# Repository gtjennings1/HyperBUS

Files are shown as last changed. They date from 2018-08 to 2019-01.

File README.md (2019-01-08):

# HyperRAM
A basic HyperRAM controller for Lattice iCE40 Ultraplus FPGAs

You can download a Verilog model of the Cypress HyperRAM from their website.
http://www.cypress.com/verilog/s27kl0641-verilog

	bitstream/	- Contains pre-synthesized and compiled FPGA bitstream and RISC-V firmware files

	radiant/		- Lattice Radiant project of the RISC-V + HyperRAM controller design

	iCEStorm/	- iCEStorm project of the RISC-V + HyperRAM controller design

	riscv32/		- picorv32 and picoSoC RISC-V files

	simulation/	- Simulation of standalone controller

	standalone/	- Simple HyperRam Controller

Sources:
RISC-V examples were based off of the PicoSoC examples provided by mmicko at the Hackaday FPGA101 Workshop.  Thank you for the great examples mmicko!
https://github.com/mmicko/fpga101-workshop

## How do I use this project

This project provide examples for APIO and iCEStorm projects and also The Lattice Radiant sotware.

### Build and upload under iCEStorm 
1. Install iCEStorm (http://www.clifford.at/icestorm/)
2. Run the following commands
    cd ./icestorm
    ./hyperram.sh
    iceprog hyperram.bin

### Build and upload under APIO project
1. Install APIO (https://github.com/FPGAwars/apio)
2. Run the following commands
    cd ./riscv32/hardware
    apio build
    apio upload

### Build and upload under Radiant software
1. Install the Laticce Radiant software (http://www.latticesemi.com/Products/DesignSoftwareAndIP/FPGAandLDS/Radiant)
2. Open radiant/riscv32_radiant.rdf file
3. Build and upload the project using the Radiant Software

### Build and upload the software for RISCV32 
1. If you use the APIO project:
    cd ./riscv32/software
    apio make
    apio make upload

2. In other cases 
   riscv64-unknown-elf-gcc -O3 -nostartfiles -mabi=ilp32 -march=rv32ic -Wl,-Bstatic,-T,sections.lds,--strip-debug -ffreestanding -o firmware.elf start.s sections.c firmware.c -lgcc
   riscv64-unknown-elf-objcopy  -O binary firmware.elf firmware.bin

3. Upload firmware.bin
* iCEStorm:
    iceprog -o 1M firmware.bin
* Radiant: upload the firmware.bin file using the programmer tool. The start address should be 1MB (see readme.md in bitstream/)

## Project Description

FPGA Project contains a RISC-V core with the hyperram controller connected.  Write and read tests are performed on the memory.

- On power up, the RGB LED will light up red
  - This insures the FPGA bitstream is loaded properly and that the RISC-V code in SPI Flash is executing.

- Shortly after words the RGB LED will flash blue or green
  - Green = read/write tests are passing
  - Blue = read/write tests are failing

Additionally, there is a UART TX port on pin 36.  If you connect it to a terminal window you can monitor the tests.  You can use the Adafruit FT232H USB board for this and connect a fly wire between pin 38 on the UPDuino and D1 and a ground wire between both boards.  Set the baud rate to 9600.

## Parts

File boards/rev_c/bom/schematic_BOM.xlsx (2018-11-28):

Qty | Value | Part Num | Package | Parts
 | DNI |  | 1X16 | J1, J2
 | DNI |  | 2X16 | J3
6 | .10uf |  | C0402 | C5, C6, C9, C10, C15, C16
1 | 0ohm |  | R0603 | R2
6 | 10uf |  | C0402 | C3, C4, C7, C8, C11, C12
 | DNI |  | HC49UP | HC49US
2 | 22pF |  | C0603 | C1, C2
3 | DNI |  | R0603 | R1, R3, R4
1 | DNI | S26KL128SDABHI030 | BGA-24 | U$1
1 | S27KL0641DABHV020 | S27KL0641DABHV020 | BGA-24 | U$2

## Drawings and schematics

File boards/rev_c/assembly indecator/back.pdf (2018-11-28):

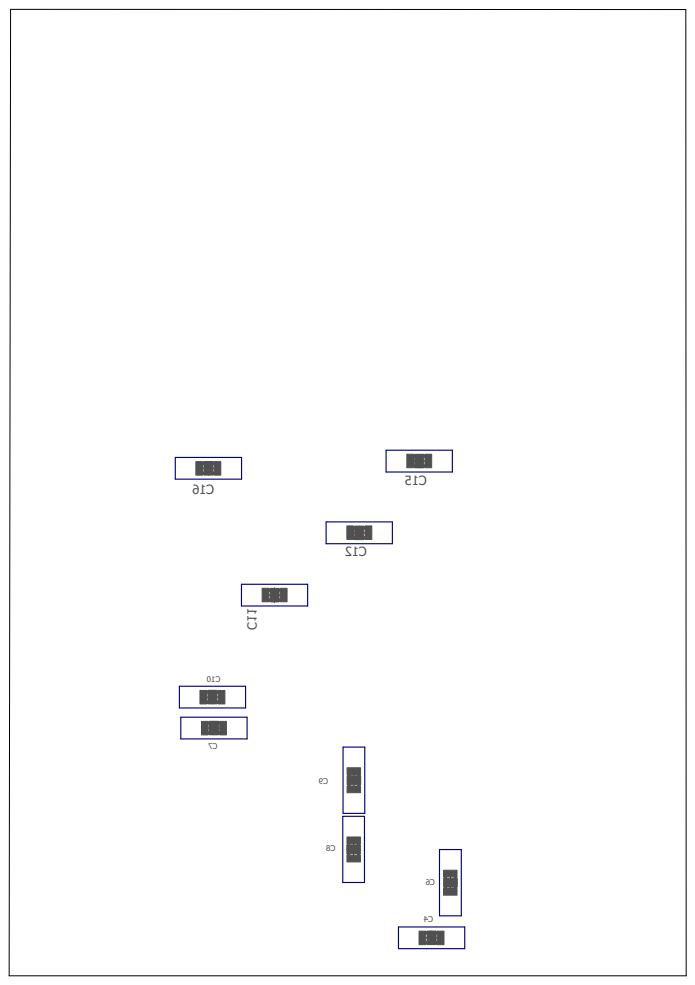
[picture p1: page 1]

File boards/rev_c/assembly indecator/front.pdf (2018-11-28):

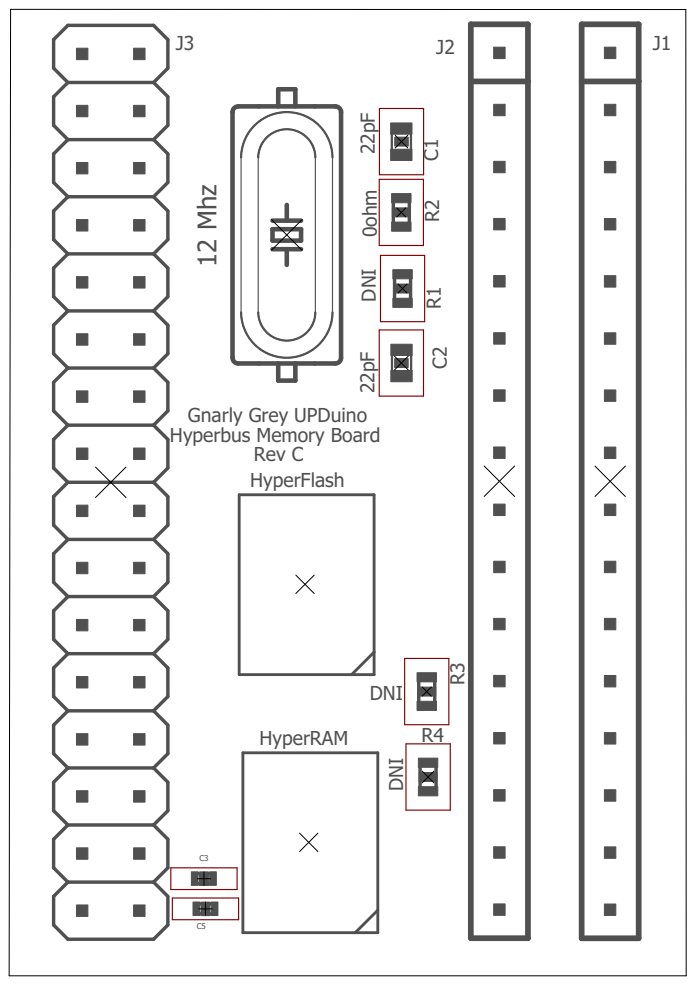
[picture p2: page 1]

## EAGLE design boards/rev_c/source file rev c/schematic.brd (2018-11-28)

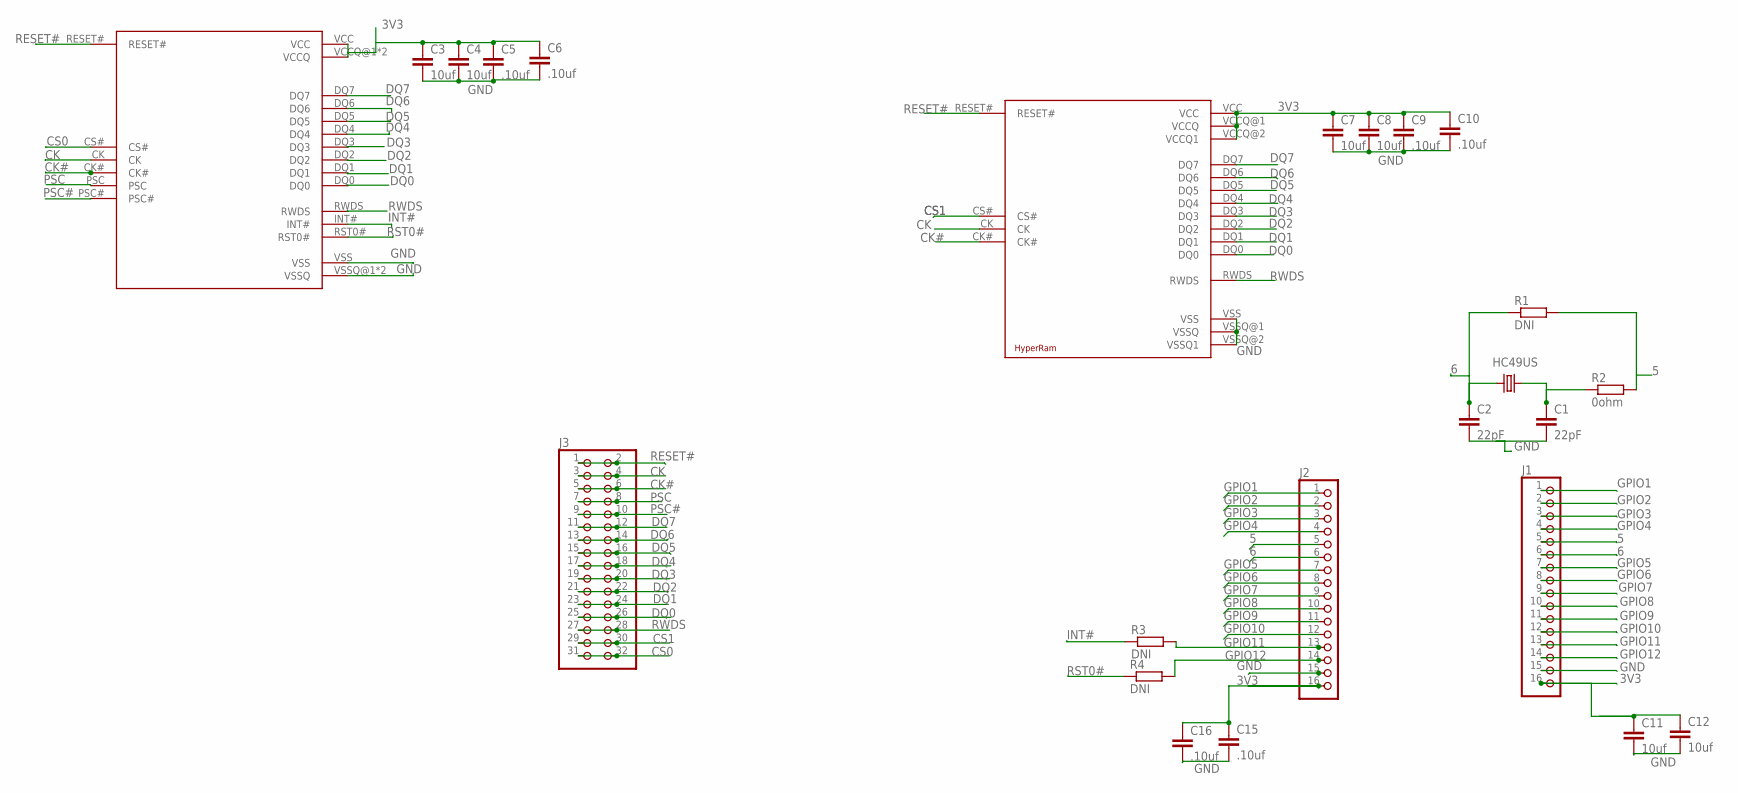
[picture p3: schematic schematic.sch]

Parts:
C1, C2: 22pF; C0603
C3, C4, C7, C8, C11, C12: 10uf; C0402
C5, C6, C9, C10, C15, C16: .10uf; C0402
HC49US: 12 Mhz; HC49UP
J1, J2: PINHD-1X16; 1X16
J3: PINHD-2X16; 2X16
R1, R3, R4: DNI; R0603
R2: 0ohm; R0603
U$1: HYPERFLASH_MEMORY; BGA-24
U$2: HYPERFLASH_MEMORY; BGA-24_RAM

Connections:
3V3: C3.1, C4.1, C5.1, C6.1, C7.1, C8.1, C9.1, C10.1, C11.1, C12.1, C15.1, C16.1, J1.16, J2.16, U$1.VCC, U$1.VCCQ@1 (VCCQ), U$1.VCCQ@2 (VCCQ), U$2.VCC, U$2.VCCQ@1 (VCCQ), U$2.VCCQ@2 (VCCQ1)
5: J1.5, J2.5, R1.2, R2.2
6: C2.1, HC49US.1, HC49US.P$1 (1), J1.6, J2.6, R1.1
CK: J3.3, J3.4, U$1.CK, U$2.CK
CK#: J3.5, J3.6, U$1.CK#, U$2.CK#
CS0: J3.31, J3.32, U$1.CS#
CS1: J3.29, J3.30, U$2.CS#
DQ0: J3.25, J3.26, U$1.DQ0, U$2.DQ0
DQ1: J3.23, J3.24, U$1.DQ1, U$2.DQ1
DQ2: J3.21, J3.22, U$1.DQ2, U$2.DQ2
DQ3: J3.19, J3.20, U$1.DQ3, U$2.DQ3
DQ4: J3.17, J3.18, U$1.DQ4, U$2.DQ4
DQ5: J3.15, J3.16, U$1.DQ5, U$2.DQ5
DQ6: J3.13, J3.14, U$1.DQ6, U$2.DQ6
DQ7: J3.11, J3.12, U$1.DQ7, U$2.DQ7
GND: C1.2, C2.2, C3.2, C4.2, C5.2, C6.2, C7.2, C8.2, C9.2, C10.2, C11.2, C12.2, C15.2, C16.2, J1.15, J2.15, U$1.VSS, U$1.VSSQ@1 (VSSQ), U$1.VSSQ@2 (VSSQ), U$2.VSS, U$2.VSSQ@1 (VSSQ), U$2.VSSQ@2 (VSSQ1)
GPIO1: J1.1, J2.1
GPIO2: J1.2, J2.2
GPIO3: J1.3, J2.3
GPIO4: J1.4, J2.4
GPIO5: J1.7, J2.7
GPIO6: J1.8, J2.8
GPIO7: J1.9, J2.9
GPIO8: J1.10, J2.10
GPIO9: J1.11, J2.11
GPIO10: J1.12, J2.12
GPIO11: J1.13, J2.13, R3.2
GPIO12: J1.14, J2.14, R4.2
INT#: R3.1, U$1.INT#
unnamed: C1.1, HC49US.2, HC49US.P$2 (2), R2.1
PSC: J3.7, J3.8, U$1.PSC
PSC#: J3.9, J3.10, U$1.PSC#
RESET#: J3.1, J3.2, U$1.RESET#, U$2.RESET#
RST0#: R4.1, U$1.RST0#
RWDS: J3.27, J3.28, U$1.RWDS, U$2.RWDS

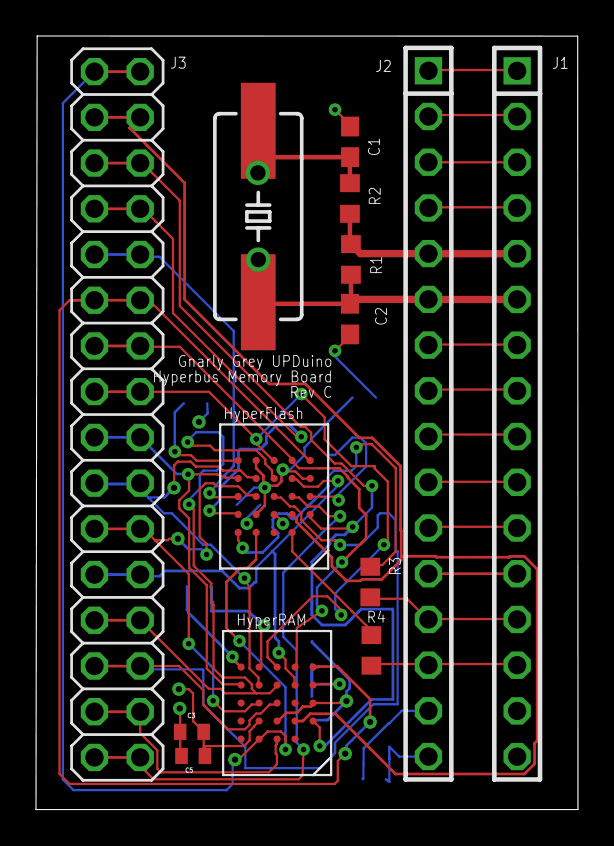
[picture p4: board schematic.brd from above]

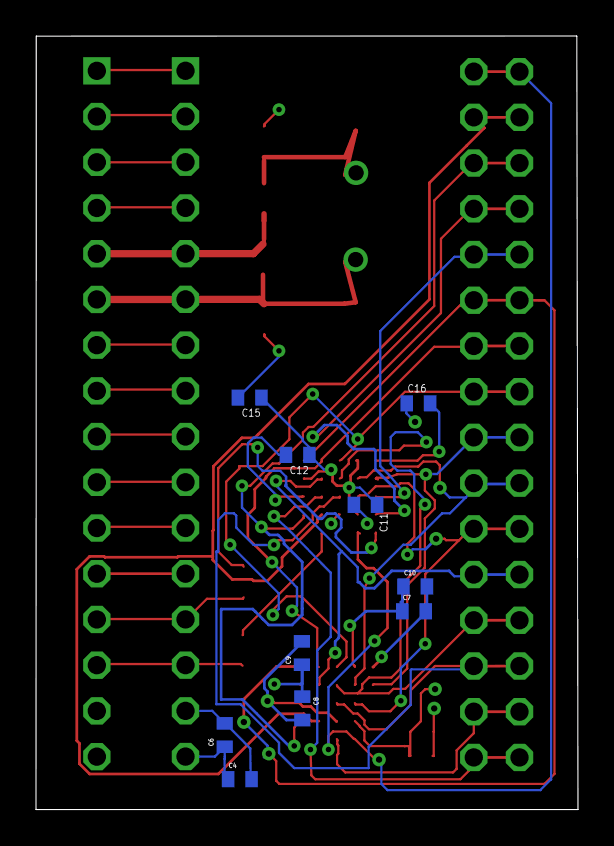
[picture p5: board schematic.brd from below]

Board: 4 copper layers, 30.1 x 43.0 mm, 24 parts (10 on the bottom side), 35 nets.

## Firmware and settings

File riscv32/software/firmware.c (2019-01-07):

// Copyright 2017 Gnarly Grey LLC

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
#include <stdint.h>
#include <stdbool.h>

#define reg_uart_clkdiv (*(volatile uint32_t*)0x02000004)
#define reg_uart_data (*(volatile uint32_t*)0x02000008)

#define reg_io   ((volatile uint32_t*)0x03000000)

#define reg0_hbc  (*(volatile uint32_t*)0x08000000)
#define reg1_hbc  (*(volatile uint32_t*)0x08000004)

#define cfg0_hbc  (*(volatile uint32_t*)0x08002000)
#define cfg1_hbc  (*(volatile uint32_t*)0x08002004)

#define WDT_START (1 << 7)
#define WDT_RESTART (WDT_START | (1 << 6) )
#define WDT_STOP (~WDT_START)
#define LED_RED (1)
#define LED_GREEN (2)
#define LED_BLUE (4)

#define PRINT_VALUES

#define TEST_8
#define TEST_16
#define TEST_32


// --------------------------------------------------------
void putchar(char c)
{
	if (c == '\n')
		putchar('\r');		
	reg_uart_data = c;
}


void print(const char *p)
{
	while (*p)
		putchar(*(p++));
}

void print_hex(uint32_t v, int digits)
{
	for (int i = 7; i >= 0; i--) {
		char c = "0123456789abcdef"[(v >> (4*i)) & 15];
		if (c == '0' && i >= digits) continue;
		putchar(c);
		digits = i;
	}
}


// --------------------------------------------------------
void main()
{
	reg_uart_clkdiv = 1250;
	

	print("\n");
	print("  ____  _          ____         ____\n");
	print(" |  _ \\(_) ___ ___/ ___|  ___  / ___|\n");
	print(" | |_) | |/ __/ _ \\___ \\ / _ \\| |\n");
	print(" |  __/| | (_| (_) |__) | (_) | |___\n");
	print(" |_|   |_|\\___\\___/____/ \\___/ \\____|\n");
	print("\n");
	print("    FPGA 101 Workshop Badge \n");
	print("    26th May - Belgrade - Hackaday\n");

	
	// start wdt and swicth on the red led
	*reg_io = WDT_START | LED_RED;

	uint32_t t, pattern = 0xDEADBEEF;
	uint8_t error;
	uint8_t test_8[128];
	uint16_t test_16[64];
	uint32_t test_32[32];

	// read IDRs
	print("IDR0: 0x");print_hex((uint16_t)(reg0_hbc), 4);print("\n");
	print("IDR1: 0x");print_hex((uint16_t)(reg1_hbc), 4);print("\n");
	
	//start test
	while(1){

#ifdef TEST_8
		
		print("uint8_t test\n");  
		for(t = 0; t < 128; t++){
			test_8[t] = (uint8_t)pattern;
			uint32_t head = (pattern >> 28);
			pattern = (pattern << 4) | head;
		}
		error = 0;
	    for(t = 0; t < 128; t++){
 			if(test_8[t] != (uint8_t)pattern) error++;
 			uint32_t head = (pattern >> 28);
			pattern = (pattern << 4) | head;
			#ifdef PRINT_VALUES
	    		print_hex(test_8[t], 2); print("\n");
	    	#else
	    		print(".");
	    	#endif
	    }

	    #ifndef PRINT_VALUES
	   		print("\n");
	   	#endif

	   	print("error: "); print_hex(error, 2); print("\n\n");

#endif
#ifdef TEST_16

	   	print("uint16_t test\n");
		for(t = 0; t < 64; t++){
			test_16[t] = (uint16_t)pattern;
			uint32_t head = (pattern >> 28);
			pattern = (pattern << 4) | head;
		}
		error = 0;
	    for(t = 0; t < 64; t++){
 			if(test_16[t] != (uint16_t)pattern) error++;
 			uint32_t head = (pattern >> 28);
			pattern = (pattern << 4) | head;
			#ifdef PRINT_VALUES
	    		print_hex(test_16[t], 4); print("\n");
	    	#else
	    		print(".");
	    	#endif
	    }
	    #ifndef PRINT_VALUES
	   		print("\n");
	   	#endif

	   	print("error: "); print_hex(error, 2); print("\n\n");
#endif
#ifdef TEST_32
	    
	    print("uint32_t test\n");
		for(t = 0; t < 32; t++){
			test_32[t] = (uint32_t)pattern;
			uint32_t head = (pattern >> 28);
			pattern = (pattern << 4) | head;
		}
		error = 0;
	    for(t = 0; t < 32; t++){
 			if(test_32[t] != (uint32_t)pattern) error++;
 			uint32_t head = (pattern >> 28);
			pattern = (pattern << 4) | head;
			#ifdef PRINT_VALUES
	    		print_hex(test_32[t], 8); print("\n");
	    	#else
	    		print(".");
	    	#endif
	    }

	    #ifndef PRINT_VALUES
	   		print("\n");
	   	#endif

	   	print("error: "); print_hex(error, 2); print("\n\n");

#endif

	   	*reg_io = WDT_RESTART | (error?LED_BLUE:LED_GREEN);
	   	
	   	print("done!\n\n");
	
    } 
}

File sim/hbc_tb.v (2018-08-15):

// Copyright 2017 Gnarly Grey LLC

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
`timescale 1ns/1ps 

module hbc_tb;

// Inputs
	reg i_clk;
	reg i_rstn;
	reg i_cfg_access;
	reg i_mem_valid;
	reg [3:0] i_mem_wstrb;
	reg [31:0] i_mem_addr;
	reg [31:0] i_mem_wdata;

	// Outputs
	wire o_mem_ready;
	wire [31:0] o_mem_rdata;
	wire o_csn0;
	wire o_csn1;
	wire o_clk;
	wire o_clkn;
	wire o_resetn;

	// Bidirs
	wire [7:0] io_dq;
	wire io_rwds;
	
	reg   [31:0] test_data [0:31];
	integer i, k;
	integer uint8_addr = 0;
	integer uint16_addr = 128;
	integer uint32_addr = 256;

hbc_wrapper hbc (
    .i_clk(i_clk), 
    .i_rstn(i_rstn), 
    .i_cfg_access(i_cfg_access), 
    .i_mem_valid(i_mem_valid), 
    .o_mem_ready(o_mem_ready), 
    .i_mem_wstrb(i_mem_wstrb), 
    .i_mem_addr(i_mem_addr), 
    .i_mem_wdata(i_mem_wdata), 
    .o_mem_rdata(o_mem_rdata), 
    .o_csn0(o_csn0), 
    .o_csn1(o_csn1), 
    .o_clk(o_clk), 
    .o_clkn(o_clkn), 
    .io_dq(io_dq), 
    .io_rwds(io_rwds), 
    .o_resetn(o_resetn)
    );
	 
s27kl0641 
	#(
	.TimingModel("S27KL0641DABHI000"))
	hyperram (
    .DQ7(io_dq[7]), 
    .DQ6(io_dq[6]), 
    .DQ5(io_dq[5]), 
    .DQ4(io_dq[4]), 
    .DQ3(io_dq[3]), 
    .DQ2(io_dq[2]), 
    .DQ1(io_dq[1]), 
    .DQ0(io_dq[0]), 
    .RWDS(io_rwds), 
    .CSNeg(o_csn0), 
    .CK(o_clk), 
    .RESETNeg(o_resetn)
    );


	initial begin
		// Initialize Inputs
		i_clk = 0;
		i_rstn = 0;
		i_cfg_access = 0;
		i_mem_valid = 0;
		i_mem_wstrb = 0;
		i_mem_addr = 0;
		i_mem_wdata = 0;

		
		#100;
      i_rstn = 1; 
		
		$display("Waiting for device power-up...");
		#160e6;
		$display("Reading the ID/CFG registers");
		
		i_cfg_access = 1;
		i_mem_valid  = 1;
		i_mem_wstrb  = 0;
		i_mem_addr   = 0;
		#10;
		i_mem_valid  = 0;
		wait(o_mem_ready == 1);
		$display("ID0: 0x%H", o_mem_rdata[15:0]);
		#20;
		i_mem_valid  = 1;
		i_mem_wstrb  = 0;
		i_mem_addr   = 2;
		#10;
		i_mem_valid  = 0;
		wait(o_mem_ready == 1);
		$display("ID1: 0x%H", o_mem_rdata[15:0]);
		#20;
		i_mem_valid  = 1;
		i_mem_wstrb  = 0;
		i_mem_addr   = 2048;
		#10;
		i_mem_valid  = 0;
		wait(o_mem_ready == 1);
		$display("CFG0: 0x%H", o_mem_rdata[15:0]);
		#20;
		i_mem_valid  = 1;
		i_mem_wstrb  = 0;
		i_mem_addr   = 2049;
		#10;
		i_mem_valid  = 0;
		wait(o_mem_ready == 1);
		$display("CFG1: 0x%H", o_mem_rdata[15:0]);
		#20;
		i_cfg_access = 0;
		test_data[0] = 32'hDEADBEEF;
		for(i = 1; i < 32; i = i + 1) begin
			test_data[i] = {test_data[i - 1][27:0], test_data[i - 1][31:28]};
		end
		#20;
		$display("UINT8_t test");
		for(i = 0; i < 32; i = i + 1) begin
			i_mem_wdata = test_data[i];
			i_mem_addr  = uint8_addr + (i << 2);
			for(k = 0; k < 4; k = k + 1) begin
				i_mem_valid = 1;
				i_mem_wstrb = (1 << k);
				#10;
				i_mem_valid = 0;
				wait(o_mem_ready == 1);
				#20;
			end
		end
		#20;
		$display("expected\tread\t\tstatus");
		i_mem_wstrb = 0;
		for(i = 0; i < 32; i = i + 1) begin
			i_mem_addr  = uint8_addr + (i << 2);
			for(k = 0; k < 4; k = k + 1) begin
				i_mem_valid = 1;
				#10;
				i_mem_valid = 0;
				wait(o_mem_ready == 1);
				if((o_mem_rdata & (255 << k*8)) == (test_data[i] & (255 << k*8))) begin
					$display("0x%H\t0x%H\tOK", (test_data[i] & (255 << k*8)), (o_mem_rdata & (255 << k*8)));
				end else begin
					$display("0x%H\t0x%H\tFAIL", (test_data[i] & (255 << k*8)), (o_mem_rdata & (255 << k*8)));
				end
				#20;
			end
		end
		#20;
		$display("UINT16_t test");
		for(i = 0; i < 32; i = i + 1) begin
			i_mem_wdata = test_data[i];
			i_mem_addr  = uint16_addr + (i << 2);
			for(k = 0; k < 2; k = k + 1) begin
				i_mem_valid = 1;
				i_mem_wstrb = (3 << (k*2));
				#10;
				i_mem_valid = 0;
				wait(o_mem_ready == 1);
				#20;
			end
		end
		#20;
		$display("expected\tread\t\tstatus");
		i_mem_wstrb = 0;
		for(i = 0; i < 32; i = i + 1) begin
			i_mem_addr  = uint8_addr + (i << 2);
			for(k = 0; k < 2; k = k + 1) begin
				i_mem_valid = 1;
				#10;
				i_mem_valid = 0;
				wait(o_mem_ready == 1);
				if((o_mem_rdata & (16'hFFFF << k*16)) == (test_data[i] & (16'hFFFF << k*16))) begin
					$display("0x%H\t0x%H\tOK", (test_data[i] & (16'hFFFF << k*16)), (o_mem_rdata & (16'hFFFF << k*16)));
				end else begin
					$display("0x%H\t0x%H\tFAIL", (test_data[i] & (16'hFFFF << k*16)), (o_mem_rdata & (16'hFFFF << k*16)));
				end
				#20;
			end
		end
		#20;
		$display("UINT32_t test");
		for(i = 0; i < 32; i = i + 1) begin
			i_mem_wdata = test_data[i];
			i_mem_addr  = uint32_addr + (i << 2);
			i_mem_valid = 1;
			i_mem_wstrb = 15;
			#10;
			i_mem_valid = 0;
			wait(o_mem_ready == 1);
			#20;
		end
		#20;
		$display("expected\tread\t\tstatus");
		i_mem_wstrb = 0;
		for(i = 0; i < 32; i = i + 1) begin
			i_mem_addr  = uint8_addr + (i << 2);
			i_mem_valid = 1;
			#10;
			i_mem_valid = 0;
			wait(o_mem_ready == 1);
			if(o_mem_rdata == test_data[i]) begin
				$display("0x%H\t0x%H\tOK", (test_data[i]), (o_mem_rdata));
			end else begin
				$display("0x%H\t0x%H\tFAIL", (test_data[i]), (o_mem_rdata));
			end
			#20;
		end
		#20;
		$stop;
	end
	
	always @(*) begin
		i_clk <= #5 ~i_clk;
	end 
	
endmodule

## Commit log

2018-08-17 added the Radiant project
    [pll.cfg]
2018-11-28 Added rev c board
    [schematic.brd, schematic.sch, schematic_BOM.xlsx]
